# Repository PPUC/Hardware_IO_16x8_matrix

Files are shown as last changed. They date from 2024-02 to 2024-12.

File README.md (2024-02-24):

# Switch Matrix PCB for PPUC Project
This is the hardware for a 16x8 switch matrix card which was designed for the PPUC pinball project, but can be useful in other applications as well. The intentionally usecase is to connect an original equipped pinball playfield (including cable harness and diodes). Normally I'd prefer direct switches but if all the switches and cables and diodes are in place already, it is useful to connect the switch matrix directly. The board can also be used for 16 direct inputs and 8 low power signal-outputs (no matrix).  
It is designed for being low cost and functional for experimental use.  
Not everything is tested nor does it fulfill EMC or any other specifications.  
Use at your own risk!
To make use of anything of this project a basic understanding of electronics and programming is necessary. Nothing of it is "plug and play". I'm surely not liable for any damage to assemblies, pinball machines or even persons.

## Picture of the Board
PCB Pic

## Name
IO_16x8_matrix as it has 16 inputs and 8 signal-outputs to form a 16x8 switch matrix but could also be used as direct inputs and low power outputs. Actually it has an additional high speed output (see "Special Output" below).  

## Power Supply
The IO card must be supplied by 5 V (+-0.5 V). In the circuit this is named 5V_IN.

## Controller
A RP2040 is used for it's cost/performance ratio. It is the same controller that is used in the Raspberry Pi Pico.

## Communication Interfaces
* RS_485: main communication interface for controlling the outputs. Usually connected to a host interface like a PC or Raspberry Pi or similar.
* USB C: for programming, debug and flashing
* Serial Wire: alternative for programming, debug and flashing

## Switches (on board)
* Reset: hardware reset for controller (RP2040)
* Boot: if active, the board connects to a PC like an USB stick. Usually used for programming the code into the flash memory on the board.
* DIP-switches: usually used to select an address for RS485 (16 combinations)

## Signal Outputs
There are 8 outputs that can be set to 5 V or GND. They are intended to drive the switch matrix (column at WPC, row at S.A.M.). The 5 V signal is derived from the 5 V supply by a 1 kOhm pull up resistor. Therefore it is only good for signaling, not for power load. If used as a matrix please be aware that every switch must have a diode in series.

## Inputs
There are 16 inputs intended to receive the switch status of the matrix (row at WPC, column at S.A.M.). They are pulled up to 5 V and switch at a voltage of about 1.9 V. The inputs are made for low active signals (switched to GND). If used as a matrix please be aware that every switch must have a diode in series.

## Special Output
One special output is available for high speed signals. The voltage is 5 V, it is a push pull output that can drive a current up to 8 mA. It can be used to e.g. control a WS2812 LED strip.

## Connectors
There are pads for connectors that fit S.A.M. systems and also WPC systems. The pinning of the returns (rows at WPC) is unfortunately vice versa to S.A.M. so the connector of the original WPC cable harness has to be rotated by 180° (cables go to the inner side of PCB).

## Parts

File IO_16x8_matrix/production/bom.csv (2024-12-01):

Designator | Footprint | Quantity | Value | LCSC Part #
C1, C10, C11, C12, C14, C15, C16, C19, C20, C23, C3, C34, C35, C36, C37, C38, C39, C40, C41, C42, C43, C44, C45, C46, C47, C48, C49, C5, C50, C51, C52, C53, C54, C55, C56, C57, C58, C8, C9 | 0402 | 39 | 100n
C13, C18 | 0402 | 2 | 1u
C17, C2, C21, C24, C33, C4 | 0603 | 6 | 10u
C22 | CP_Elec_6.3x7.7 | 1 | 100µ 35V
C25, C26, C27, C28, C29, C30, C31, C32 | 0603 | 8 | 10n
C6, C7 | 0402 | 2 | 27pF
D1, D2 | D_SOD-323 | 2 | SD15
D10, D11, D12, D13, D14, D15, D16, D17, D18, D19, D20, D21, D22, D7, D8, D9 | D_SOD-323 | 16 | 1N4148WS
D23, D3 | D_SOD-323 | 2 | 1A
D4 | 0805 | 1 | LED gn
D5 | D_SMA | 1 | SMAJ5.0
D6 | D_SOD-323 | 1 | SD05
J1, J4 | Terminal_Block_RTMPin | 2 | Conn_01x06
J3 | USB_C_Receptacle_XKB_U262-16XN-4BVC11 | 1 | USB_C_Receptacle_USB2.0
J6 | Molex_KK-396_5273-09A_1x09_P3.96mm_Vertical | 1 | Conn_01x09
J8, J9 | Molex_KK-396_5273-10A_1x10_P3.96mm_Vertical | 2 | Conn_01x10
JP1 | PinHeader_1x02_P2.54mm_Vertical | 1 | Jumper_2_Open
Q1, Q2, Q3, Q4, Q5, Q6, Q7, Q8 | SOT-23 | 8 | MMBT3904
R1, R10, R11, R18, R38, R39, R44, R45, R50, R51, R65, R66, R7, R71, R72, R77, R78, R8, R83, R84, R89, R90 | 0603 | 22 | 10k
R12, R13 | 0402 | 2 | 27
R14, R19, R58, R6, R62 | 0402 | 5 | 1k
R15, R2, R40, R41, R46, R47, R52, R53, R67, R68, R73, R74, R79, R80, R85, R86, R91, R92 | 0603 | 18 | 100R
R16, R17 | 0603 | 2 | 5k1
R20, R21, R22, R23, R24, R25, R26, R27, R28, R29, R30, R31, R32, R33, R34, R35, R42, R43, R48, R49, R54, R55, R69, R70, R75, R76, R81, R82, R87, R88, R93, R94 | 0603 | 32 | 1k
R36, R37, R57, R60, R61, R64 | 0603 | 6 | 2k
R4 | 0603 | 1 | 120R
R56 | 0603 | 1 | 33k
R59 | 0603 | 1 | 5k
R63 | 0603 | 1 | 3k
R9 | 0603 | 1 | 0
SW1 | SW_SPST_SKQG_WithStem | 1 | Reset
SW2 | SW_SPST_SKQG_WithStem | 1 | Boot
SW3 | SW_DIP_SPSTx04_Slide_6.7x11.72mm_W8.61mm_P2.54mm_LowProfile | 1 | ADDRESS
U1 | SOIC-8_3.9x4.9mm_P1.27mm | 1 | ADM3483
U14 | SOT-23-5 | 1 | LMV321
U2 | SOIC-8_5.23x5.23mm_P1.27mm | 1 | W25Q128JVSIQ
U3 | QFN-56-1EP_7x7mm_P0.4mm_EP3.2x3.2mm | 1 | RP2040
U4 | SOT-23-5 | 1 | SN74AHCT1G125
U5 | SOT-23-5 | 1 | AP2112K-3.3
U6, U7, U8, U9 | SOIC-14_3.9x8.7mm_P1.27mm | 4 | LM339
Y1 | Crystal_SMD_3225-4Pin_3.2x2.5mm | 1 | 12MHz,18pF

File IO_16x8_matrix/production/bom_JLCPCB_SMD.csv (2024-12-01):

Designator | Footprint | Quantity | Value | LCSC Part #
C1, C10, C11, C12, C14, C15, C16, C19, C20, C23, C3, C34, C35, C36, C37, C38, C39, C40, C41, C42, C43, C44, C45, C46, C47, C48, C49, C5, C50, C51, C52, C53, C54, C55, C56, C57, C58, C8, C9 | 0402 | 39 | 100n | C1525
C13, C18 | 0402 | 2 | 1u | C52923
C17, C2, C21, C24, C33, C4 | 0603 | 6 | 10u | C19702
C22 | CP_Elec_6.3x7.7 | 1 | 100µ 35V | C2836437
C25, C26, C27, C28, C29, C30, C31, C32 | 0603 | 8 | 10n | C57112
C6, C7 | 0402 | 2 | 27pF | C1557
D1, D2 | D_SOD-323 | 2 | SD15 | C502529
D10, D11, D12, D13, D14, D15, D16, D17, D18, D19, D20, D21, D22, D7, D8, D9 | D_SOD-323 | 16 | 1N4148WS | C2128
D23, D3 | D_SOD-323 | 2 | 1A | C191023
D4 | 0805 | 1 | LED gn | C2297
D5 | D_SMA | 1 | SMAJ5.0 | C2925443
D6 | D_SOD-323 | 1 | SD05 | C2972756
J3 | USB_C_Receptacle_XKB_U262-16XN-4BVC11 | 1 | USB_C_Receptacle_USB2.0 | C709357
Q1, Q2, Q3, Q4, Q5, Q6, Q7, Q8 | SOT-23 | 8 | MMBT3904 | C20526
R1, R10, R11, R18, R38, R39, R44, R45, R50, R51, R65, R66, R7, R71, R72, R77, R78, R8, R83, R84, R89, R90 | 0603 | 22 | 10k | C25804
R12, R13 | 0402 | 2 | 27 | C138021
R14, R19, R58, R6, R62 | 0402 | 5 | 1k | C11702
R15, R2, R40, R41, R46, R47, R52, R53, R67, R68, R73, R74, R79, R80, R85, R86, R91, R92 | 0603 | 18 | 100R | C22775
R16, R17 | 0603 | 2 | 5k1 | C23186
R20, R21, R22, R23, R24, R25, R26, R27, R28, R29, R30, R31, R32, R33, R34, R35, R42, R43, R48, R49, R54, R55, R69, R70, R75, R76, R81, R82, R87, R88, R93, R94 | 0603 | 32 | 1k | C21190
R36, R37, R57, R60, R61, R64 | 0603 | 6 | 2k | C22975
R4 | 0603 | 1 | 120R | C22787
R56 | 0603 | 1 | 33k | C4216
R59 | 0603 | 1 | 5k | C101077
R63 | 0603 | 1 | 3k | C4211
R9 | 0603 | 1 | 0 | C21189
SW1 | SW_SPST_SKQG_WithStem | 1 | Reset | C318884
SW2 | SW_SPST_SKQG_WithStem | 1 | Boot | C318884
SW3 | SW_DIP_SPSTx04_Slide_6.7x11.72mm_W8.61mm_P2.54mm_LowProfile | 1 | ADDRESS | C54950
U1 | SOIC-8_3.9x4.9mm_P1.27mm | 1 | ADM3483 | C609792
U14 | SOT-23-5 | 1 | LMV321 | C7972
U2 | SOIC-8_5.23x5.23mm_P1.27mm | 1 | W25Q128JVSIQ | C97521
U3 | QFN-56-1EP_7x7mm_P0.4mm_EP3.2x3.2mm | 1 | RP2040 | C2040
U4 | SOT-23-5 | 1 | SN74AHCT1G125 | C7484
U5 | SOT-23-5 | 1 | AP2112K-3.3 | C51118
U6, U7, U8, U9 | SOIC-14_3.9x8.7mm_P1.27mm | 4 | LM339 | C179558
Y1 | Crystal_SMD_3225-4Pin_3.2x2.5mm | 1 | 12MHz,18pF | C9002

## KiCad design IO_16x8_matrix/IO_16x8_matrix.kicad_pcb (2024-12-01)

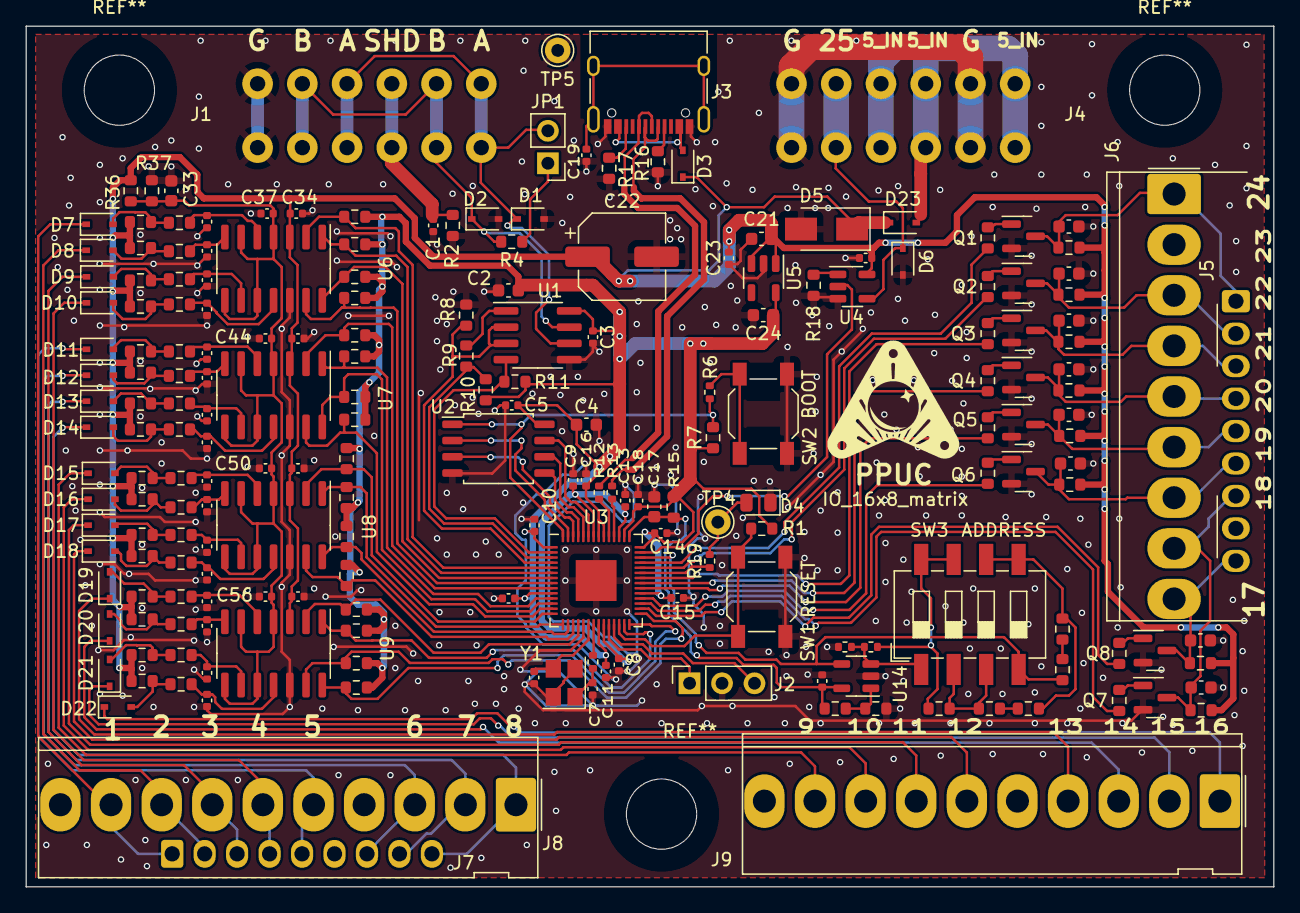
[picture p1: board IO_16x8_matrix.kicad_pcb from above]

Board: 2 copper layers, 97.6 x 67.3 mm, 207 parts (0 on the bottom side), 137 nets.

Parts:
C1, C3, C5, C8, C9, C10, C11, C12, C14, C15, C16, C19, C20, C23, C34, C35, C36, C37, C38, C39, C40, C41, C42, C43, C44, C45, C46, C47, C48, C49, C50, C51, C52, C53, C54, C55, C56, C57, C58: 100n; C_0402_1005Metric
C2, C4, C17, C21, C24, C33: 10u; C_0603_1608Metric
C6, C7: 27pF; C_0402_1005Metric
C13, C18: 1u; C_0402_1005Metric
C22: 100µ 35V; CP_Elec_6.3x7.7
C25, C26, C27, C28, C29, C30, C31, C32: 10n; C_0603_1608Metric
D1, D2: SD15; D_SOD-323
D3, D23: 1A; D_SOD-323
D4: LED gn; LED_0805_2012Metric
D5: SMAJ5.0; D_SMA
D6: SD05; D_SOD-323
D7, D8, D9, D10, D11, D12, D13, D14, D15, D16, D17, D18, D19, D20, D21, D22: 1N4148WS; D_SOD-323
J1, J4: Conn_01x06; Terminal_Block_RTMPin
J2: nmount SW Debug; PinSocket_1x03_P2.54mm_Vertical
J3: USB_C_Receptacle_USB2.0; USB_C_Receptacle_XKB_U262-16XN-4BVC11
J5, J7: Conn_01x09; Molex_KK-254_AE-6410-09A_1x09_P2.54mm_Vertical
J6: Conn_01x09; Molex_KK-396_5273-09A_1x09_P3.96mm_Vertical
J8, J9: Conn_01x10; Molex_KK-396_5273-10A_1x10_P3.96mm_Vertical
JP1: Jumper_2_Open; PinHeader_1x02_P2.54mm_Vertical
Q1, Q2, Q3, Q4, Q5, Q6, Q7, Q8: MMBT3904; SOT-23
R1, R7, R8, R10, R11, R18, R38, R39, R44, R45, R50, R51, R65, R66, R71, R72, R77, R78, R83, R84, R89, R90: 10k; R_0603_1608Metric
R2, R15, R40, R41, R46, R47, R52, R53, R67, R68, R73, R74, R79, R80, R85, R86, R91, R92: 100R; R_0603_1608Metric
R4: 120R; R_0603_1608Metric
R6, R14, R19, R58, R62: 1k; R_0402_1005Metric
R9: 0; R_0603_1608Metric
R12, R13: 27; R_0402_1005Metric
R16, R17: 5k1; R_0603_1608Metric
R20, R21, R22, R23, R24, R25, R26, R27, R28, R29, R30, R31, R32, R33, R34, R35, R42, R43, R48, R49, R54, R55, R69, R70, R75, R76, R81, R82, R87, R88, R93, R94: 1k; R_0603_1608Metric
R36, R37, R57, R60, R61, R64: 2k; R_0603_1608Metric
R56: 33k; R_0603_1608Metric
R59: 5k; R_0603_1608Metric
R63: 3k; R_0603_1608Metric
SW1: Reset; SW_SPST_SKQG_WithStem
SW2: Boot; SW_SPST_SKQG_WithStem
SW3: ADDRESS; SW_DIP_SPSTx04_Slide_6.7x11.72mm_W8.61mm_P2.54mm_LowProfile
TP4: TP_LED; Pin_D1.0mm_L10.0mm
TP5: TP_GND; Pin_D1.0mm_L10.0mm
U1: ADM3483; SOIC-8_3.9x4.9mm_P1.27mm
U2: W25Q128JVSIQ; SOIC-8_5.23x5.23mm_P1.27mm
U3: RP2040; QFN-56-1EP_7x7mm_P0.4mm_EP3.2x3.2mm
U4: SN74AHCT1G125; SOT-23-5
U5: AP2112K-3.3; SOT-23-5
U6, U7, U8, U9: LM339; SOIC-14_3.9x8.7mm_P1.27mm
U14: LMV321; SOT-23-5
Y1: 12MHz,18pF; Crystal_SMD_3225-4Pin_3.2x2.5mm

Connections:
+3V3: C2.1, C3.1, C4.1, C5.1, C10.1, C11.1, C12.1, C14.1, C15.1, C16.1, C18.1, C24.1, R1.2, R7.1, R10.1, R11.1, R15.1, R38.1, R39.1, R44.1, R45.1, R50.1, R51.1, R65.1, R66.1, R71.1, R72.1, R77.1, R78.1, R83.1, R84.1, R89.1, R90.1, U1.8 (VCC), U2.8 (VCC), U3.1 (IOVDD), U3.10 (IOVDD), U3.22 (IOVDD), U3.33 (IOVDD), U3.42 (IOVDD), U3.44 (VREG_IN), U3.48 (USB_VDD), U3.49 (IOVDD), U5.5 (VOUT)
+5V: C20.1, C21.1, C22.1, C23.1, C34.1, C40.1, C47.1, C53.1, D3.1 (K), D5.1 (K), D23.1 (K), R24.1, R25.1, R26.1, R27.1, R32.1, R33.1, R34.1, R35.1, R36.1, R42.1, R43.1, R48.1, R49.1, R54.1, R55.1, R69.1, R70.1, R75.1, R76.1, R81.1, R82.1, R87.1, R88.1, R93.1, R94.1, U4.5 (VCC), U5.1 (VIN), U5.3 (EN), U6.3 (V+), U7.3 (V+), U8.3 (V+), U9.3 (V+)
/1V1: C8.1, C9.1, C13.1, U3.23 (DVDD), U3.45 (VREG_VOUT), U3.50 (DVDD)
/3V3A: C17.1, C42.1, R15.2, R56.1, U3.43 (ADC_AVDD), U14.5 (V+)
/5V_IN: D23.2 (A), J4.1, J4.3, J4.4
/485_DE: R8.2, U1.2 (~RE), U1.3 (DE), U3.4 (GPIO2)
/485_RX: R9.2, R10.2, U3.3 (GPIO1)
/485_TX: R11.2, U1.4 (DI), U3.2 (GPIO0)
/A: D1.1 (K), J1.1, J1.4, JP1.2 (B), U1.6 (A)
/B: D2.1 (K), J1.2, J1.5, R4.2, U1.7 (B)
/Driver8/D1: C25.1, J5.1, J6.1, Q1.3 (C), R24.2
/Driver8/D2: C26.1, J5.2, J6.3, Q2.3 (C), R25.2
/Driver8/D3: C27.1, J5.3, J6.4, Q3.3 (C), R26.2
/Driver8/D4: C28.1, J5.4, J6.5, Q4.3 (C), R27.2
/Driver8/D5: C29.1, J5.5, J6.6, Q5.3 (C), R32.2
/Driver8/D6: C30.1, J5.6, J6.7, Q6.3 (C), R33.2
/Driver8/D7: C31.1, J5.7, J6.8, Q7.3 (C), R34.2
/Driver8/D8: C32.1, J5.9, J6.9, Q8.3 (C), R35.2
/In16/T1: D7.1 (K), J7.1, J8.9
/In16/T2: D8.1 (K), J7.2, J8.8
/In16/T3: D9.1 (K), J7.3, J8.7
/In16/T4: D10.1 (K), J7.4, J8.6
/In16/T5: D11.1 (K), J7.5, J8.5
/In16/T6: D12.1 (K), J7.7, J8.3
/In16/T7: D13.1 (K), J7.8, J8.2
/In16/T8: D14.1 (K), J7.9, J8.1
/In16/T9: D15.1 (K), J9.9
/In16/T10: D16.1 (K), J9.8
/In16/T11: D17.1 (K), J9.7
/In16/T12: D18.1 (K), J9.6
/In16/T13: D19.1 (K), J9.4
/In16/T14: D20.1 (K), J9.3
/In16/T15: D21.1 (K), J9.2
/In16/T16: D22.1 (K), J9.1
/In16/V_SWITCH: C33.1, C37.1, C44.1, C50.1, C56.1, R36.2, R37.1, U6.4 (-), U6.6 (-), U6.8 (-), U6.10 (-), U7.4 (-), U7.6 (-), U7.8 (-), U7.10 (-), U8.4 (-), U8.6 (-), U8.8 (-), U8.10 (-), U9.4 (-), U9.6 (-), U9.8 (-), U9.10 (-)
/In_1: R38.2, U3.5 (GPIO3), U6.2
/In_2: R39.2, U3.6 (GPIO4), U6.1
/In_3: R44.2, U3.7 (GPIO5), U6.14
/In_4: R45.2, U3.8 (GPIO6), U6.13
/In_5: R50.2, U3.9 (GPIO7), U7.2
/In_6: R51.2, U3.11 (GPIO8), U7.1
/In_7: R65.2, U3.12 (GPIO9), U7.14
/In_8: R66.2, U3.13 (GPIO10), U7.13
/In_9: R71.2, U3.14 (GPIO11), U8.2
/In_10: R72.2, U3.15 (GPIO12), U8.1
/In_11: R77.2, U3.16 (GPIO13), U8.14
/In_12: R78.2, U3.17 (GPIO14), U8.13
/In_13: R83.2, U3.18 (GPIO15), U9.2
/In_14: R84.2, U3.27 (GPIO16), U9.1
/In_15: R89.2, U3.28 (GPIO17), U9.14
/In_16: R90.2, U3.29 (GPIO18), U9.13
/Out_1: R20.1, U3.39 (GPIO27_ADC1)
/Out_2: R21.1, U3.38 (GPIO26_ADC0)
/Out_3: R22.1, U3.36 (GPIO24)
/Out_4: R23.1, U3.35 (GPIO23)
/Out_5: R28.1, U3.34 (GPIO22)
/Out_6: R29.1, U3.32 (GPIO21)
/Out_7: R30.1, U3.31 (GPIO20)
/Out_8: R31.1, U3.30 (GPIO19)
/Out_S: D6.1 (K), J4.5, U4.4
/Out_Special: U3.41 (GPIO29_ADC3), U4.2
/Q_SCLK: U2.6 (CLK), U3.52 (QSPI_SCLK)
/Q_nCS: R6.2, R7.2, U2.1 (~CS), U3.56 (QSPI_SS)
/SHD: C1.1, J1.3, R2.1
/USB_D+: J3.A6 (D+), J3.B6 (D+), R12.1
/USB_D-: J3.A7 (D-), J3.B7 (D-), R13.1
/V_addr: R59.1, SW3.4, U3.40 (GPIO28_ADC2), U14.4
/nReset: R1.1, SW1.2, U3.26 (RUN)
GND: C1.2, C2.2, C3.2, C4.2, C5.2, C6.1, C7.1, C8.2, C9.2, C10.2, C11.2, C12.2, C13.2, C14.2, C15.2, C16.2, C17.2, C18.2, C19.2, C20.2, C21.2, C22.2, C23.2, C24.2, C25.2, C26.2, C27.2, C28.2, C29.2, C30.2, C31.2, C32.2, C33.2, C34.2, C35.2, C36.2, C37.2, C38.2, C39.2, C40.2, C41.2, C42.2, C43.2, C44.2, C45.2, C46.2, C47.2, C48.2, C49.2, C50.2, C51.2, C52.2, C53.2, C54.2, C55.2, C56.2, C57.2, C58.2, D1.2 (A), D2.2 (A), D4.1 (K), D5.2 (A), D6.2 (A), J1.6, J2.2, J3.A1 (GND), J3.A12 (GND), J3.B1 (GND), J3.B12 (GND), J4.2, J4.6, Q1.2 (E), Q2.2 (E), Q3.2 (E), Q4.2 (E), Q5.2 (E), Q6.2 (E), Q7.2 (E), Q8.2 (E), R2.2, R8.1, R16.2, R17.2, R18.2, R37.2, R57.2, R58.2, SW1.1, SW2.1, TP5.1, U1.5 (GND), U2.4 (GND), U3.19 (TESTEN), U3.57 (GND), U4.3 (GND), U5.2 (GND), U6.12 (V-), U7.12 (V-), U8.12 (V-), U9.12 (V-), U14.2 (V-), Y1.2, Y1.4
unnamed: C6.2, U3.20 (XIN), Y1.3
unnamed: C7.2, R14.1, Y1.1
unnamed: C19.1, J3.S1 (SHIELD)
unnamed: C35.1, R40.1, U6.5 (+)
unnamed: C36.1, R41.1, U6.7 (+)
unnamed: C38.1, R46.1, U6.9 (+)
unnamed: C39.1, R47.1, U6.11 (+)
unnamed: C41.1, R52.1, U7.5 (+)
unnamed: C43.1, R53.1, U7.7 (+)
unnamed: C45.1, R67.1, U7.9 (+)
unnamed: C46.1, R68.1, U7.11 (+)
unnamed: C48.1, R73.1, U8.5 (+)
unnamed: C49.1, R74.1, U8.7 (+)
unnamed: C51.1, R79.1, U8.9 (+)
unnamed: C52.1, R80.1, U8.11 (+)
unnamed: C54.1, R85.1, U9.5 (+)
unnamed: C55.1, R86.1, U9.7 (+)
unnamed: C57.1, R91.1, U9.9 (+)
unnamed: C58.1, R92.1, U9.11 (+)
unnamed: D3.2 (A), J3.A4 (VBUS), J3.A9 (VBUS), J3.B4 (VBUS), J3.B9 (VBUS)
unnamed: D4.2 (A), R19.2, TP4.1
unnamed: D7.2 (A), R40.2, R42.2
unnamed: D8.2 (A), R41.2, R43.2
unnamed: D9.2 (A), R46.2, R48.2
unnamed: D10.2 (A), R47.2, R49.2
unnamed: D11.2 (A), R52.2, R54.2
unnamed: D12.2 (A), R53.2, R55.2
unnamed: D13.2 (A), R67.2, R69.2
unnamed: D14.2 (A), R68.2, R70.2
unnamed: D15.2 (A), R73.2, R75.2
unnamed: D16.2 (A), R74.2, R76.2
unnamed: D17.2 (A), R79.2, R81.2
unnamed: D18.2 (A), R80.2, R82.2
unnamed: D19.2 (A), R85.2, R87.2
unnamed: D20.2 (A), R86.2, R88.2
unnamed: D21.2 (A), R91.2, R93.2
unnamed: D22.2 (A), R92.2, R94.2
unnamed: J2.1, U3.24 (SWCLK)
unnamed: J2.3, U3.25 (SWD)
unnamed: J3.A5 (CC1), R16.1
unnamed: J3.B5 (CC2), R17.1
unnamed: Q1.1 (B), R20.2
unnamed: Q2.1 (B), R21.2
unnamed: Q3.1 (B), R22.2
unnamed: Q4.1 (B), R23.2
unnamed: Q5.1 (B), R28.2
unnamed: Q6.1 (B), R29.2
unnamed: Q7.1 (B), R30.2
unnamed: Q8.1 (B), R31.2
unnamed: JP1.1 (A), R4.1
unnamed: R6.1, SW2.2
unnamed: R9.1, U1.1 (RO)
unnamed: R12.2, U3.47 (USB_DP)
unnamed: R13.2, U3.46 (USB_DM)
unnamed: R14.2, U3.21 (XOUT)
unnamed: R18.1, U4.1
unnamed: R19.1, U3.37 (GPIO25)
unnamed: R56.2, R57.1, U14.1 (+)
unnamed: R58.1, R62.1, SW3.1, U14.3 (-)
unnamed: R59.2, R63.1
unnamed: R60.1, R61.1, SW3.2, SW3.3
unnamed: R60.2, R64.1
unnamed: R61.2, R62.2, SW3.7, SW3.8
unnamed: R63.2, R64.2, SW3.5, SW3.6
unnamed: U2.2 (DO(IO1)), U3.55 (QSPI_SD1)
unnamed: U2.3 (IO2), U3.54 (QSPI_SD2)
unnamed: U2.5 (DI(IO0)), U3.53 (QSPI_SD0)
unnamed: U2.7 (IO3), U3.51 (QSPI_SD3)

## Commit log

2024-03-26 opt routing
    [Drv8.kicad_sch, IO_16x8_matrix.kicad_pcb, IO_16x8_matrix.kicad_sch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]
2024-03-27 added csvs
    [IO_16x8_matrix.csv, bom.csv, bom_handbearbeitet_bak.csv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]
2024-03-27 cleaned up
    [bom_handbearbeitet_bak.csv]
